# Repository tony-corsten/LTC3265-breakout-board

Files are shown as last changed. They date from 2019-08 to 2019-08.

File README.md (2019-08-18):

# LTC3265-breakout-board
# Overview
The LTC3265 is a compact, low-noise, potentially quad rail supply utilizing a charge-pump architecture with input voltage from 4V - 16V and output voltages of approximately -32V - 32V (total output current of 50mV). The main difference between the LTC3265 and the LTC3260 is that the LTC3265 has a boost regulator on the input, making it ideal for high voltage supplies (e.g., +/- 15V from a 9V input). The chip can have up to four outputs: 1) a doubled input voltage output, 2) an inverted output (either from the input or doubled input voltage), 3) & 4) a positive and negative LDO. This makes it extremely versatile for boards that require either very low noise dual rails for op amps, or multiple dual rails for high-powered devices that are more noise tolerant. [You can find the official documentation for the chip here](https://www.analog.com/en/products/ltc3265.html). This is a breakout board made in Kicad with a barrel jack power input [(the PJ-037A)](https://www.digikey.com/product-detail/en/cui-inc/PJ-037A/CP-037A-ND/1644545) and 2.54mm through holes for output voltages (your choice of header pins or a screw terminal block!)

*_Note_*: The board is currently designed for a +/- 15V rail for a 9V battery input. You can adjust the output voltage by tweaking the setting resistors, RLDOP1/2 and RDLON1/2. The ratio is described on pages 12/13 of the technical manual. 

# Navigating this repo
The main folder contains relevant Kicad files (.pro, .pcb, .sch). The `gerber` directory has a PCB-fabrication ready set of gerber files. The `library` directory contains a custom kicad footprint for the PJ-037A. 

# Board images
PCB Layout:
PCB Layout

Schematic:
Schematic

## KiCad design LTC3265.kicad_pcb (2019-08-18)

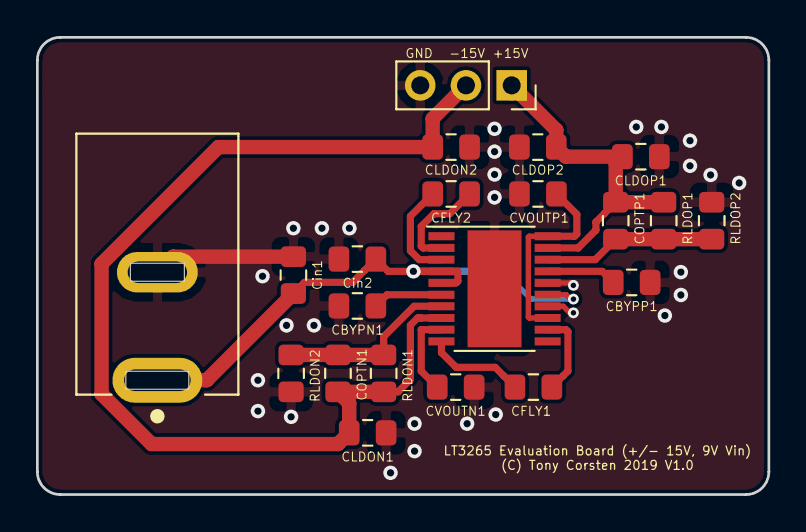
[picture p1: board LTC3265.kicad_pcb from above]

Board: 2 copper layers, 40.6 x 25.4 mm, 21 parts (0 on the bottom side), 14 nets.

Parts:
CBYPN1: 0.1uF; C_0805_2012Metric_Pad1.15x1.40mm_HandSolder
CBYPP1: 0.1uF; C_0805_2012Metric_Pad1.15x1.40mm_HandSolder
CFLY1, CFLY2: 1uF; C_0805_2012Metric_Pad1.15x1.40mm_HandSolder
CLDON1: 2uF; C_0805_2012Metric_Pad1.15x1.40mm_HandSolder
CLDON2: 0.1uF; C_0805_2012Metric_Pad1.15x1.40mm_HandSolder
CLDOP1: 2uF; C_0805_2012Metric_Pad1.15x1.40mm_HandSolder
CLDOP2: 0.1uF; C_0805_2012Metric_Pad1.15x1.40mm_HandSolder
COPTN1: 10pF; C_0805_2012Metric_Pad1.15x1.40mm_HandSolder
COPTP1: 10pF; C_0805_2012Metric_Pad1.15x1.40mm_HandSolder
CVOUTN1: 10uF; C_0805_2012Metric_Pad1.15x1.40mm_HandSolder
CVOUTP1: 10uF; C_0805_2012Metric_Pad1.15x1.40mm_HandSolder
Cin1: 10uF; C_0805_2012Metric_Pad1.15x1.40mm_HandSolder
Cin2: 0.1uF; C_0805_2012Metric_Pad1.15x1.40mm_HandSolder
J1: Barrel_Jack; PJ-037A
J2: Conn_01x03_Male; PinSocket_1x03_P2.54mm_Vertical
RLDON1: 604k; R_0805_2012Metric_Pad1.15x1.40mm_HandSolder
RLDON2: 52.3k; R_0805_2012Metric_Pad1.15x1.40mm_HandSolder
RLDOP1: 604k; R_0805_2012Metric_Pad1.15x1.40mm_HandSolder
RLDOP2: 52.3k; R_0805_2012Metric_Pad1.15x1.40mm_HandSolder
U1: LTC3265EFE; HTSSOP-20-1EP_4.4x6.5mm_P0.65mm_EP3x6.5mm

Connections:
+9V: Cin1.1, Cin2.1, J1.1, U1.4, U1.5, U1.15
/+15V: CLDOP1.1, CLDOP2.1, COPTP1.2, J2.1, RLDOP1.1, U1.19
/-15V: CLDON1.2, CLDON2.1, COPTN1.1, J2.2, RLDON1.2, U1.8
/ADJ+: COPTP1.1, RLDOP1.2, RLDOP2.2, U1.18
/ADJ-: COPTN1.2, RLDON1.1, RLDON2.2, U1.7
/BYP+: CBYPP1.2, U1.17
/BYP-: CBYPN1.2, U1.6
/VOUT+: CVOUTP1.2, U1.13, U1.20
GND: CBYPN1.1, CBYPP1.1, CLDON1.1, CLDON2.2, CLDOP1.2, CLDOP2.2, CVOUTN1.2, CVOUTP1.1, Cin1.2, Cin2.2, J1.2, J2.3, RLDON2.1, RLDOP2.1, U1.14, U1.16, U1.21
unnamed: CFLY1.1, U1.10
unnamed: CFLY1.2, U1.12
unnamed: CFLY2.1, U1.2
unnamed: CFLY2.2, U1.3
unnamed: CVOUTN1.1, U1.9
